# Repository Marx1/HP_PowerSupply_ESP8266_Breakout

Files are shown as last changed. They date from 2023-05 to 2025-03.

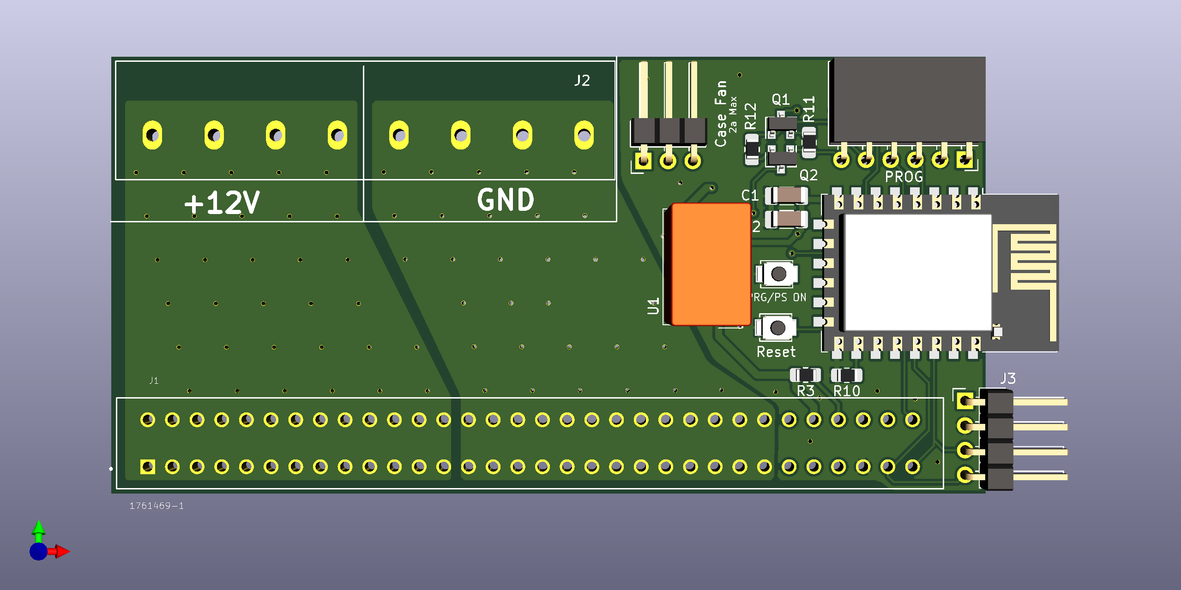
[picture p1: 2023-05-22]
PCB Top.png

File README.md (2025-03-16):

# HP Power supply (up to 1200w*) breakout board w/ ESP8266 
(I use ESPhome and that is the example included) to control the Power supply remotely. 

**WARNING: This code is designed to use custom components with ESPhome, a feature that was removed. I do not have a work around for this at this time.**

These are commonly used in the holiday lighting community (as I am on my show), so the features are geared towards this.

## Features include

- PSMBus control/management of the power supply
  - PS Temps (There are two sensors) monitoring (in Fahrenheit)
  - AC Voltage, current (Amps) and power (watts) monitoring
  - DC Voltage, current (Amps) and power (watts) monitoring
  - PSU Fan speed monitoring and control.
  - PSU model detection (common PSU names pre-mapped in code)
- Analog measurement of power (As a backup in the event the PSMBus is not working/incompatible)
- PSU Failure/Alarm support (There is no real use for this outside of a PSU fan failure)
- Local and remote power supply power control
- Case/Box fan control for up to 2a of fans using standard PC style 3/4 pin fans. Protected with Polyfuse, powered even with PSU is off.
- Environmental monitoring option via BME280 (Or any other i2c sensor via a header)
- Wifi signal strength

## Some notes about this design

- There is no real feedback about PSU state outside of the PSU LED, I felt it wasn't needed on the board as you can usually see the PSU LED.
- There is no feedback on Case/Box Fan status, but you usually can see the fan operating or not; most users don't use this unless you're in the south or California.
- There is a 900W (75a) power limit.  This is designed around a 1200w ps running on 120v.*
- 30a max per output connector
- 10awg max size per output connector
- Wire ferrules are recommend
- Torque output connector to 5 in-lbs.

### Technical bits and bobs around the notes
* The board has a power limit of **900w continuous draw (75a)** it *should* be ok with higher draws for VERY Short periods (IE accidentally setting lights to all white). This is because the 64 pin PSU Connector from TE is rated at 3 amps a pin, and there are 26 pins per +12v and Gnd, resulting in 78a, The traces are designed around a 25c temp rise, with the PSU fan sucking air over it all the time, this should be fine. I'm sourcing real TE high-power connectors, HP may have some proprietary connectors that can handle more power, but a 1200w power supply requires 240v to output it's full power - and most people don't do that.

Each of the output connectors are rated at 32a, but 10awg is the max wire size, so its really 30a. You should use wire Ferrules and torque the connectors to 5 in-lb at high currents. Over torquing can break them.

The code for the common slot PS is forked from https://github.com/hitsword/csps_esphome

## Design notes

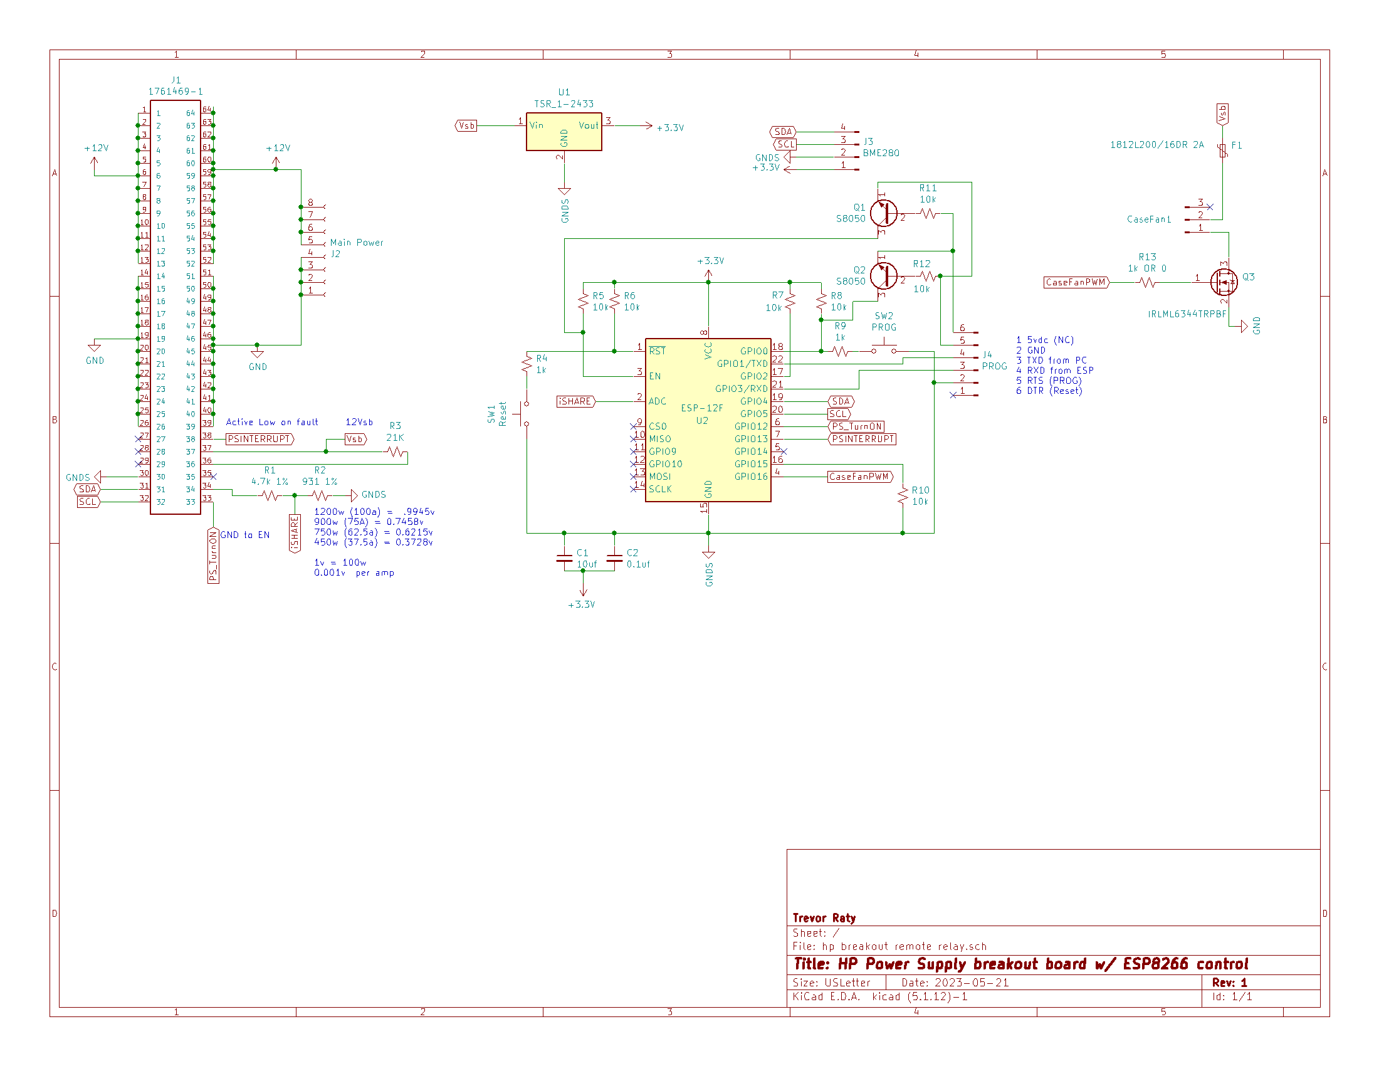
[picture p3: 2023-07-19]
schematic.png

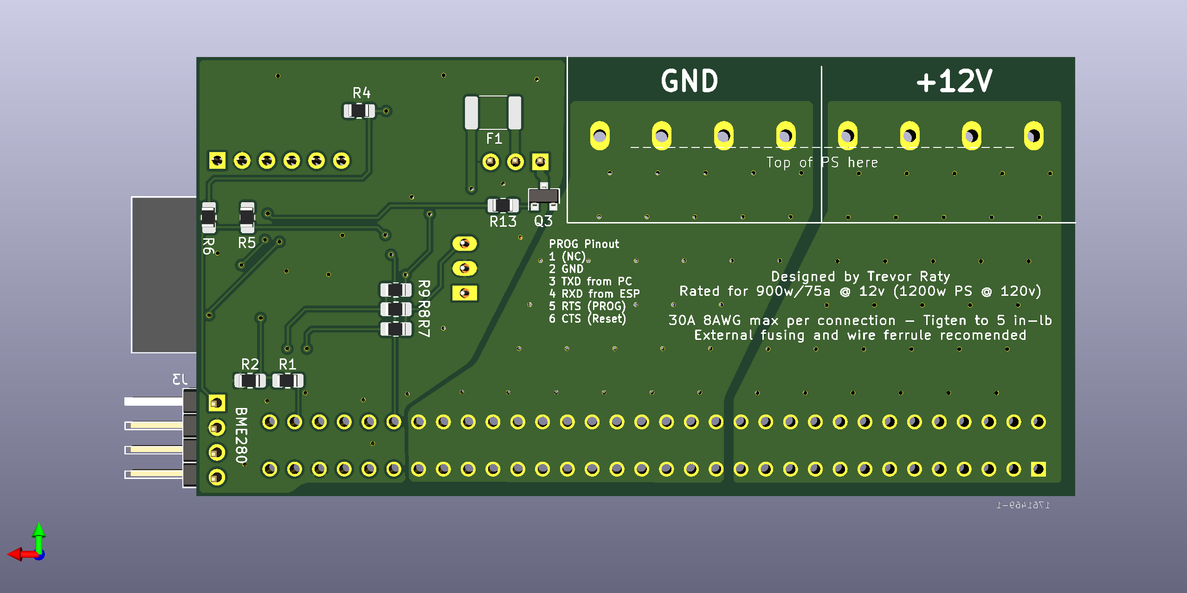
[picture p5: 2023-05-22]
PCB Bottom.png

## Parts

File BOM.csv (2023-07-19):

Source: | C:\Users\traty\Dropbox\3 -- Maker stuff\PCB\hp breakout\hp breakout remote relay.sch
Date: | 5/11/2023 7:05:24 PM
Tool: | Eeschema (5.1.12)-1
Generator: | C:\Program Files\KiCad\bin\scripting\plugins/bom_csv_grouped_by_value.py
Component Count: | 28
Individual Components:
Item | Qty | Reference(s) | Value | LibPart | Footprint | Datasheet | Field4 | Field5 | Field6
 |  | C1 | 10uf | Device:C_Small | Capacitor_SMD:C_1206_3216Metric_Pad1.33x1.80mm_HandSolder | ~
 |  | C2 | 0.1uf | Device:C_Small | Capacitor_SMD:C_1206_3216Metric_Pad1.33x1.80mm_HandSolder | ~
 |  | CaseFan1 | Conn_01x02_Male | Connector:Conn_01x02_Male | Connector_TE-Connectivity:2_position_6.35mm_header | ~
 |  | F1 | 1812L200/16DR 2A | Device:Polyfuse_Small | Fuse:Fuse_1812_4532Metric_Pad1.30x3.40mm_HandSolder | ~
 |  | J1 | 1761469-1 | hp-breakout-rescue:1761469-1-TE1761469 | Connector_TE-Connectivity:TE_1761469-1 | Manufacturer Recommendations | TE Connectivity | D2 | http://www.te.com/commerce/DocumentDelivery/DDEController?Action=showdoc
 |  | J2 | +12v | Connector:Conn_01x04_Female | Connector_TE-Connectivity:4_position_6.35mm_header | ~
 |  | J3 | GND | Connector:Conn_01x04_Female | Connector_TE-Connectivity:4_position_6.35mm_header | ~
 |  | J4 | BME280 | Connector:Conn_01x04_Male | Connector_PinHeader_2.54mm:PinHeader_1x04_P2.54mm_Horizontal | ~
 |  | J5 | PROG | Connector:Conn_01x06_Male | Connector_PinHeader_2.54mm:PinHeader_1x06_P2.54mm_Vertical | ~
 |  | Q1 | S8050 | Transistor_BJT:S8050 | Package_TO_SOT_THT:TO-92_Inline | http://www.unisonic.com.tw/datasheet/S8050.pdf
 |  | Q2 | S8050 | Transistor_BJT:S8050 | Package_TO_SOT_THT:TO-92_Inline | http://www.unisonic.com.tw/datasheet/S8050.pdf
 |  | Q3 | IRLML6344TRPBF | Transistor_FET:IRLML0030 | Package_TO_SOT_SMD:SOT-23 | https://www.infineon.com/dgdl/irlml0030pbf.pdf?fileId=5546d462533600a401535664773825df
 |  | R1 | 1.74k 1% | Device:R_Small_US | Resistor_SMD:R_0805_2012Metric_Pad1.20x1.40mm_HandSolder | ~
 |  | R2 | 2k 1% | Device:R_Small_US | Resistor_SMD:R_0805_2012Metric_Pad1.20x1.40mm_HandSolder | ~
 |  | R3 | 21K | Device:R_Small_US | Resistors_THT:R_Axial_DIN0204_L3.6mm_D1.6mm_P5.08mm_Horizontal | ~
 |  | R4 | 1k | Device:R_Small_US | Resistor_SMD:R_0805_2012Metric_Pad1.20x1.40mm_HandSolder | ~
 |  | R5 | 10k | Device:R_Small_US | Resistor_SMD:R_0805_2012Metric_Pad1.20x1.40mm_HandSolder | ~
 |  | R6 | 10k | Device:R_Small_US | Resistor_SMD:R_0805_2012Metric_Pad1.20x1.40mm_HandSolder | ~
 |  | R7 | 10k | Device:R_Small_US | Resistor_SMD:R_0805_2012Metric_Pad1.20x1.40mm_HandSolder | ~
 |  | R8 | 10k | Device:R_Small_US | Resistor_SMD:R_0805_2012Metric_Pad1.20x1.40mm_HandSolder | ~
 |  | R9 | 1k | Device:R_Small_US | Resistor_SMD:R_0805_2012Metric_Pad1.20x1.40mm_HandSolder | ~
 |  | R10 | 10k | Device:R_Small_US | Resistor_SMD:R_0805_2012Metric_Pad1.20x1.40mm_HandSolder | ~
 |  | R11 | 10k | Device:R_Small_US | Resistor_SMD:R_0805_2012Metric_Pad1.20x1.40mm_HandSolder | ~
 |  | R12 | 10k | Device:R_Small_US | Resistor_SMD:R_0805_2012Metric_Pad1.20x1.40mm_HandSolder | ~
 |  | SW1 | Reset | Switch:SW_Push | Button_Switch_SMD:SW_SPST_B3U-1000P | ~
 |  | SW2 | PROG | Switch:SW_Push | Button_Switch_SMD:SW_SPST_B3U-1000P | ~
 |  | U1 | TSR_1-2433 | Regulator_Switching:TSR_1-2433 | Converter_DCDC:Converter_DCDC_TRACO_TSR-1_THT | http://www.tracopower.com/products/tsr1.pdf
 |  | U2 | ESP-12F | RF_Module:ESP-12F | RF_Module:ESP-12E | http://wiki.ai-thinker.com/_media/esp8266/esp8266_series_modules_user_manual_v1.1.pdf
Collated Components:
Item | Qty | Reference(s) | Value | LibPart | Footprint | Datasheet | Field4 | Field5 | Field6
1 | 1 | C1 | 10uf | Device:C_Small | Capacitor_SMD:C_1206_3216Metric_Pad1.33x1.80mm_HandSolder | ~
2 | 1 | C2 | 0.1uf | Device:C_Small | Capacitor_SMD:C_1206_3216Metric_Pad1.33x1.80mm_HandSolder | ~
3 | 1 | CaseFan1 | Conn_01x02_Male | Connector:Conn_01x02_Male | Connector_TE-Connectivity:2_position_6.35mm_header | ~
4 | 1 | F1 | 1812L200/16DR 2A | Device:Polyfuse_Small | Fuse:Fuse_1812_4532Metric_Pad1.30x3.40mm_HandSolder | ~
5 | 1 | J1 | 1761469-1 | hp-breakout-rescue:1761469-1-TE1761469 | Connector_TE-Connectivity:TE_1761469-1 | Manufacturer Recommendations | TE Connectivity | D2 | http://www.te.com/commerce/DocumentDelivery/DDEController?Action=showdoc
6 | 1 | J2 | +12v | Connector:Conn_01x04_Female | Connector_TE-Connectivity:4_position_6.35mm_header | ~
7 | 1 | J3 | GND | Connector:Conn_01x04_Female | Connector_TE-Connectivity:4_position_6.35mm_header | ~
8 | 1 | J4 | BME280 | Connector:Conn_01x04_Male | Connector_PinHeader_2.54mm:PinHeader_1x04_P2.54mm_Horizontal | ~
9 | 1 | J5 | PROG | Connector:Conn_01x06_Male | Connector_PinHeader_2.54mm:PinHeader_1x06_P2.54mm_Vertical | ~
10 | 2 | Q1, Q2 | S8050 | Transistor_BJT:S8050 | Package_TO_SOT_THT:TO-92_Inline | http://www.unisonic.com.tw/datasheet/S8050.pdf
11 | 1 | Q3 | IRLML6344TRPBF | Transistor_FET:IRLML0030 | Package_TO_SOT_SMD:SOT-23 | https://www.infineon.com/dgdl/irlml0030pbf.pdf?fileId=5546d462533600a401535664773825df
12 | 1 | R1 | 1.74k 1% | Device:R_Small_US | Resistor_SMD:R_0805_2012Metric_Pad1.20x1.40mm_HandSolder | ~
13 | 1 | R2 | 2k 1% | Device:R_Small_US | Resistor_SMD:R_0805_2012Metric_Pad1.20x1.40mm_HandSolder | ~
14 | 1 | R3 | 21K | Device:R_Small_US | Resistors_THT:R_Axial_DIN0204_L3.6mm_D1.6mm_P5.08mm_Horizontal | ~
15 | 2 | R4, R9 | 1k | Device:R_Small_US | Resistor_SMD:R_0805_2012Metric_Pad1.20x1.40mm_HandSolder | ~
16 | 7 | R5, R6, R7, R8, R10, R11, R12 | 10k | Device:R_Small_US | Resistor_SMD:R_0805_2012Metric_Pad1.20x1.40mm_HandSolder | ~
17 | 1 | SW1 | Reset | Switch:SW_Push | Button_Switch_SMD:SW_SPST_B3U-1000P | ~
18 | 1 | SW2 | PROG | Switch:SW_Push | Button_Switch_SMD:SW_SPST_B3U-1000P | ~
19 | 1 | U1 | TSR_1-2433 | Regulator_Switching:TSR_1-2433 | Converter_DCDC:Converter_DCDC_TRACO_TSR-1_THT | http://www.tracopower.com/products/tsr1.pdf
20 | 1 | U2 | ESP-12F | RF_Module:ESP-12F | RF_Module:ESP-12E | http://wiki.ai-thinker.com/_media/esp8266/esp8266_series_modules_user_manual_v1.1.pdf

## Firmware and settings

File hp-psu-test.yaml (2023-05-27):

substitutions:
  update_time: 30s
  devicename: hp-psu-test
  ip_address: 1.1.1.1
  gateway: 1.1.1.1
  subnet: 255.255.255.0
  dns: 8.8.8.8
  
# GPIO4: SDA
# GPIO5: SCL
# GPIO12: PS turnon (Low to turn on)
# GPIO13: PS Inturrupt ( Low on fault )
# GPIO14: Fan RPM/Tach (pulled high externally)
# GPIO16: Fan PWM Out
# ADC0: iShare (Analog current shunt)
#        1200w (100a) =  3.216v
#        900w (75A) = 2.412v
#        750w (62.5a) = 2.010v
#        450w (37.5a) = 1.206v


wifi: 
  ssid: "a cool ssid"
  password: "a password"
  domain: .a.tld
  reboot_timeout: 1min
  manual_ip:
    static_ip: ${ip_address}
    gateway: ${gateway}
    subnet: ${subnet}
    dns1: ${dns}
    

esphome:
  name: ${devicename}
  platform: esp8266
  board: esp12e
  includes:
    - CSPS/main.hpp
    - CSPS/KCORES_CSPS.h
    - CSPS/KCORES_CSPS.cpp
    
  libraries:
    - "Wire"
    
# Enable logging
logger:
  level: debug


# Enable Home Assistant API
api:
  encryption:
   key: !secret api_key
ota:
   safe_mode: true
   password: !secret ota_key

i2c:
   sda: 4
   scl: 5
   scan: true

switch:
  #GPIO to trigger PSU Turn-on
  - platform: gpio
    pin: 
      number: 12
    inverted: true
    id: PSU_power
    name: "${devicename} PSU Power"

fan:
  #fan speed control via IRLML6344TRPBF Mosfet 
  - platform: speed
    name: "${devicename} Box Fan"
    output: fan_gpio16
    id: fan1
    speed_count: 10

number:
  - platform: template
    id: csps_rpm
    device_class: speed
    unit_of_measurement: 'RPM'
    name: "${devicename} PSU Fan RPM"
    optimistic: true
    min_value: 0
    max_value: 20000
    step: 500
    on_value:
      then:
        - lambda: |-
            auto power = new CSPSPower();
            App.register_component(power);
            power->set_fan_rpm(id(csps_rpm).state);


output:
  #Fan Speed control. Tune Min_Power to the lowest your fan will spin at, and max_power should  be just above the point where the fan is fully on (should be 1)
  - platform: esp8266_pwm
    pin: 16
    frequency: 20000 Hz
    id: fan_gpio16
    min_power: .4
    max_power: 1
    zero_means_zero: true


#--------------- Returns power supply model number. If your's isn't listed, Add a new substitute statement. Just a personal thing to help ID power supplies.
text_sensor:
  - platform: custom
    lambda: |-
      auto power = new CSPSPower();
      App.register_component(power);
      return{power->sparepart};
    text_sensors:
    - name: "${devicename} Power Supply Model"
      filters:
      - substitute:
        - "511777-001 -> HP DPS-460EB 460w/38.3a"
        - "660184-01 -> HP HSTNS-PR28 460w/38.3a"
        - "511777-001 -> HP DPS-750AB-3 750w/62.2a"
        - "643932-001 -> HP HSTNS-PL29 750w/62.2a"
        - "660185-001 -> HP DPS-1200SB 1200w/100a(240v) 900w/75a(120v)"
        - "498152-001 -> HP HSTNS-PL11 1200w/100a(240v) 900w/75a(120v)" 


binary_sensor:
  # PS Inturrupt, not used right mow. Goes low when there is a PSU error.
  - platform: gpio
    pin: 
      number: 13
      inverted: true
      mode:
        input: true
        pullup: False
    name: "${devicename} PSInturrupt"
    
  #re-use FLASH/PROG button to act as local PSU control once booted
  # Single press= PSU on/off
  # Short hold = Case Fan On/Off
  # Long Hold = PSU Fan Max speed/Auto
  - platform: gpio
    pin: 
      number: 0
      inverted: true
    name: "${devicename} Local PSU Control"
    icon: mdi:pushbutton
    on_click:
    - min_length: 50ms
      max_length: 350ms
      then:
        - switch.toggle: PSU_power
    - min_length: 1000ms
      max_length: 5000ms
      then:
        lambda: |-
          if (id(csps_rpm).state == 0 ) {
            auto call = id(csps_rpm).make_call();
            call.set_value(20000);
            call.perform();
          } else {
            auto call = id(csps_rpm).make_call();
            call.set_value(0);
            call.perform();
          }
    - min_length: 350ms
      max_length: 1000ms
      then:
        lambda: |-
          if (id(fan1).state) {
            auto call = id(fan1).turn_off();
            call.perform();
          } else {
            auto call = id(fan1).turn_on();
            call.set_speed(10);
            call.perform();
          }

sensor: 
  - platform: wifi_signal
    name: "${devicename} wifi signal"
    update_interval: $update_time

  #analog current (Used for backup/validation from PSMbus)
  - platform: ct_clamp
    sensor: adc_sensor
    name: "${devicename} Analog DC Current"
    update_interval: $update_time
    device_class: power
    filters:
      - calibrate_linear:
          # Measured value of 0 maps to 0A
          - 0 -> 0
          - 0.3728 -> 37.5
          - 0.6215 -> 62.5
          - 0.7458 -> 75
          - 0.9945 -> 100


  # ADC input for current
  - platform: adc
    pin: A0
    id: adc_sensor
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
